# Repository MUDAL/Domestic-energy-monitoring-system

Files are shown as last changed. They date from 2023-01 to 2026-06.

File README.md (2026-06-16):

# Energy-monitoring-system

## Description  
This repository contains the code, schematics, videos, and documentation for a domestic energy monitoring system.   
The system is designed to measure and display current, voltage, power, and energy consumption at different   
points in a building, allowing users to monitor their energy usage in real-time.   

## Features   
1. Measurement of current, voltage, power, and energy consumed in a building.
2. Periodic display of measured data on an LCD.
3. Periodic logging of measured data on an SD card.
4. Periodic data upload to the cloud (ThingSpeak Server and Google Sheets).
5. Wi-Fi provisioning: To configure the SSID and password of the Wi-Fi network required by the system via a captive portal.
The captive portal also configures voltage, current, power, and energy limits.
6. The device sends notifications to the user (via an MQTT mobile application) whenever the measured parameters exceed their limits.    

## Hardware  
1. ESP32 development board  
2. PZEM-004T power module  
3. 16x2 LCD   
4. DS3231 RTC module  
5. SD card module   
6. 2GB SD card  
7. AC power socket
8. 3-pin AC power plug   
9. Jumper wires  
10. LM7805 voltage regulator  
11. LM2596 buck converter module  
12. Logic level shifter  
13. SPDT switch
14. 9V AC adapter   

## Software  
The system was developed using the ESP-IDF FreeRTOS software platform. The ESP32 was programmed using C++.    
The code provides real-time measurement and display of current, voltage, power, and energy consumption,  
as well as data logging to an SD card and data upload to the ThingSpeak server and Google Sheets.  

The software tools used in this project include:
1. Arduino IDE  
2. ESP-IDF FreeRTOS: To execute different tasks concurrently  
3. ThingSpeak: To visualize data  
4. IFTTT: To upload data to Google Sheets   
5. MQTT Alert: A mobile app to notify the user when energy limits have been exceeded.    
The smart energy monitor sends notifications to an MQTT broker (HiveMQ was used).    
The mobile app receives these notifications from the broker and alerts the user.  

Link to download the ``MQTT Alert`` application: https://play.google.com/store/apps/details?id=gigiosoft.MQTTAlert  

## Software architecture  
<p align="center">
    
</p> 

## Video Demos  
1. [System Startup](https://drive.google.com/file/d/15rAykP7Cj1u7JRBl1Hu21nxwTJwd_Z20/view?usp=sharing)  
2. [WiFi Provisioning](https://drive.google.com/file/d/1VSvE99P1S9wBY2bUv_U48mo-3ODMSw2Y/view?usp=sharing)  
3. [Load Test: Electric Iron](https://drive.google.com/file/d/1FuSU22RljI5VVFWzha-J6OE0soTpG5kJ/view?usp=sharing)  
4. [Load Test: Light Bulb](https://drive.google.com/file/d/1OdBM0wIGSkZ7wZ5bF1eTk2QWKEQir789/view?usp=sharing)  
5. [Data Logging](https://drive.google.com/file/d/1yUPShkziFqxqBmcSKSHpU0T5GiAVOwqM/view?usp=sharing)  

## Images of the prototype   

Screenshot (380)
Screenshot (382)  
Screenshot (378)  
yy  
    


     

## Credits  
1. https://randomnerdtutorials.com/esp32-esp8266-publish-sensor-readings-to-google-sheets/  
2. https://github.com/stechiez/iot_projects/blob/master/GoogleSpreadSheet_ESP32_IFTTT/ESP32_GoogleSpreadSheetIFTTT/ESP32_GoogleSpreadSheetIFTTT.ino  
3. PZEM-004T sample code and connections: https://www.nn-digital.com/en/blog/2019/11/04/example-of-the-pzem-004t-v3-v3-0-interfacing-program-using-arduino/  

## Note(s)  
1. ``preferences.begin("T-Mon",false);``. I observed that a short string as the first argument    
of ``begin`` method helps in avoiding some issues with accessing the flash memory via the   
``Preferences`` library. ``T-Mon`` was used as a short form for ``Transformer-monitor``.  
The initial application of this project was transformer monitoring but the requirements changed  
and the system was designed to monitor electrical parameters in a residential building. ``T-Mon``  
was retained but the current application of the system is ``domestic energy monitoring``.  
 
## Recommendation(s)  
1. Add a feature to prevent users from removing the SD card each time they need to view their logged data.  
One way this could be achieved is the use of ``FTP`` for file transfer from the system to a connected device  
(e.g. a PC) which will run an FTP server software.  
Another option is to set the system up as a local server that will enable other devices to download the file  
containing the logged data through a web browser.  

## Improvements made  
1. Display of ``0`` instead of ``NAN`` whenever the system isn't plugged.  
2. Replacement of code utilizing dynamic memory allocation with code utilizing static memory allocation.  
3. Replacement of batteries with an AC adapter for power supply (final modification).

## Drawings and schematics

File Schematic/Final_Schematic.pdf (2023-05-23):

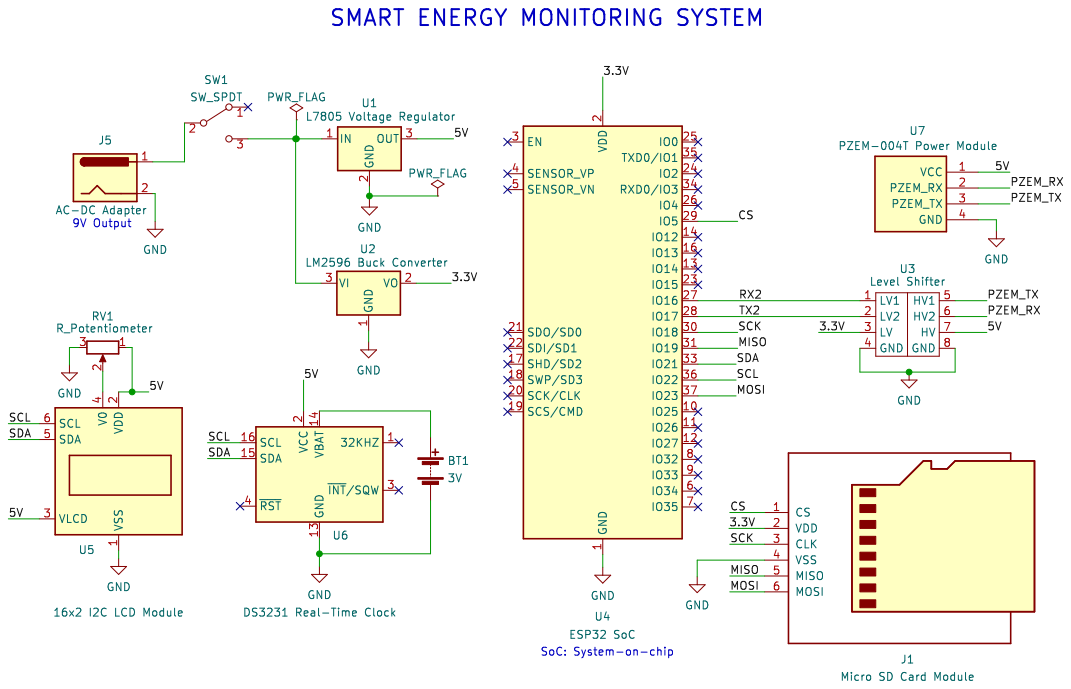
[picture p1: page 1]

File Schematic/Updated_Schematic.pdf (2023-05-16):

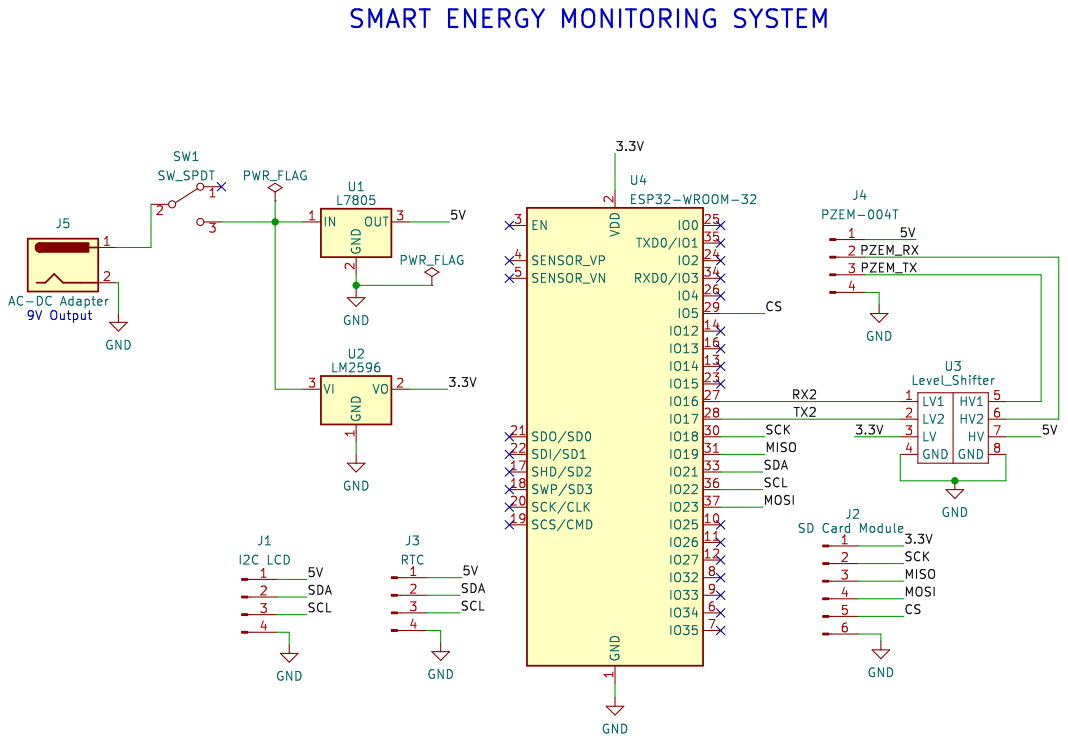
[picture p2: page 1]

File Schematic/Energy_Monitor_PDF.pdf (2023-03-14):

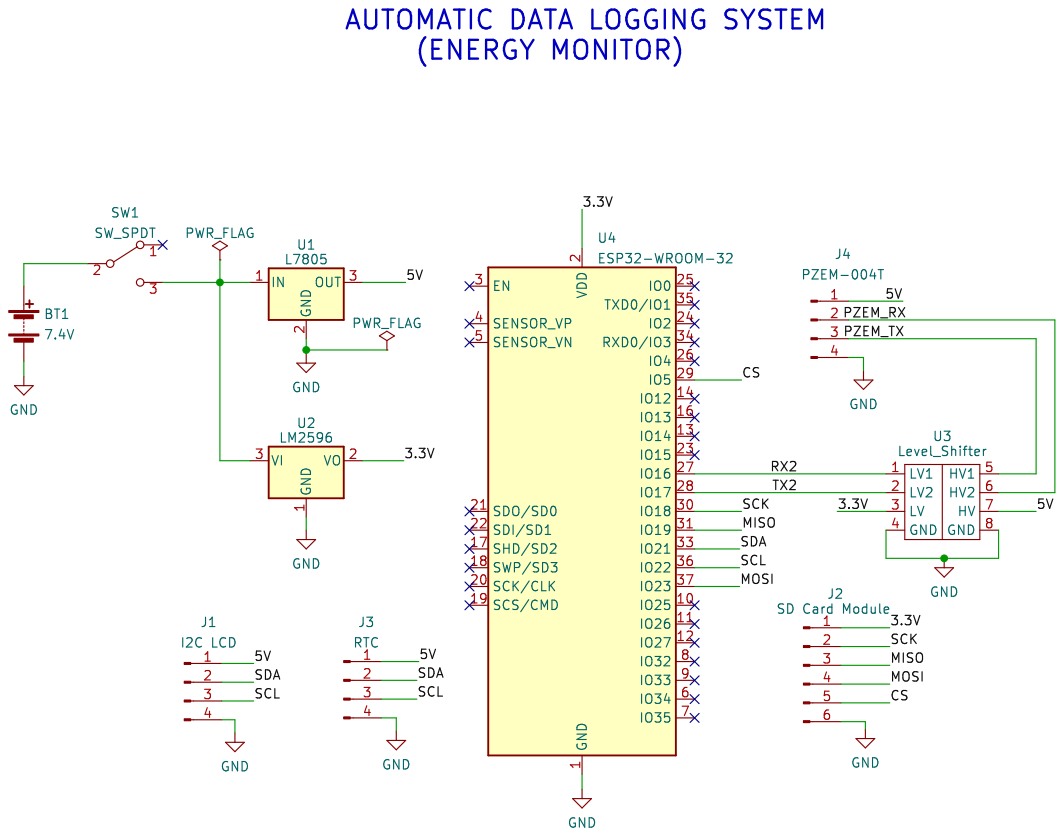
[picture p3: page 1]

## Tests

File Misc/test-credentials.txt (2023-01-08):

IFTTT:
Event name: Data
API Key: v4XEsEC37_EedkIpFihIbAvMPWIc17FXT786lTl9he

ThingSpeak:
Channel ID: 1144356
API key: 6GKXGMG5WRE8WK70

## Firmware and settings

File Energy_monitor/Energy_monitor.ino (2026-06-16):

// Author: Olaoluwa Raji

#include <WiFi.h>
#include <HTTPClient.h>
#include <Preferences.h>
#include <WiFiManager.h>
#include <PubSubClient.h>
#include <Wire.h>
#include <PZEM004Tv30.h>
#include <LiquidCrystal_I2C.h> //Version 1.1.2
#include "ThingSpeak.h" //Version 2.0.1
#include "RTClib.h" //Version 1.3.3
#include "FS.h"
#include "SD.h"
#include "SPI.h"
#include "numeric_lib.h"

//Maximum number of characters
#define SIZE_EVENT_NAME        20
#define SIZE_IFTTT_KEY         50
#define SIZE_CHANNEL_ID        30
#define SIZE_API_KEY           50
#define SIZE_TOPIC             30
#define SIZE_VOLTAGE            7
#define SIZE_CURRENT            7
#define SIZE_POWER             11
#define SIZE_ENERGY            11 
#define SIZE_CLIENT_ID         23

//Shared resources
WiFiManagerParameter eventName("0","Event name","",SIZE_EVENT_NAME);
WiFiManagerParameter iftttKey("1","IFTTT key","",SIZE_IFTTT_KEY);
WiFiManagerParameter channelId("2","ThingSpeak channel ID","",SIZE_CHANNEL_ID);
WiFiManagerParameter apiKey("3","ThingSpeak API key","",SIZE_API_KEY);
WiFiManagerParameter pubTopic("4","HiveMQ Publish topic","",SIZE_TOPIC);
WiFiManagerParameter voltageLimit("5","Voltage limit (V)","",SIZE_VOLTAGE);
WiFiManagerParameter currentLimit("6","Current limit (A)","",SIZE_CURRENT);
WiFiManagerParameter powerLimit("7","Power limit (W)","",SIZE_POWER);
WiFiManagerParameter energyLimit("8","Energy limit (kWh)","",SIZE_ENERGY);
WiFiManagerParameter subTopic("9","HiveMQ Subscription topic","",SIZE_TOPIC);
WiFiManagerParameter clientID("A","MQTT client ID","",SIZE_CLIENT_ID);
Preferences preferences; //for accessing ESP32 flash memory

//Global variables
bool isWifiTaskSuspended = false;
float pzemVoltage = 0; //in volts
float pzemCurrent = 0; //in amps
float pzemPower = 0; //in watts
float pzemEnergy = 0; //in kWh 
bool isThingSpeakOk = false;
bool isIftttOk = false;
uint8_t resetEnergyCounter = 0; //Set if data is received from MQTT broker to reset PZEM's energy counter
bool isEnergyReset = false; //Set if PZEM's energy counter was successfully reset

//Task handle(s)
TaskHandle_t wifiTaskHandle;
TaskHandle_t dispLogTaskHandle;
TaskHandle_t mqttTaskHandle;

/**
 * @brief Make an HTTP GET request to the specified server
*/
static void HttpGetRequest(const char* serverName,int* httpResponseCode) 
{ 
  HTTPClient http;
  http.begin(serverName);
  *httpResponseCode = http.GET();
  http.end();  
}

/**
 * @brief Store new data (e.g. IFTTT and ThingSpeak credentials) to specified 
 * location in ESP32's flash memory if the new credentials are different from 
 * the previous.  
*/
static void StoreNewFlashData(const char* flashLoc,const char* newData,
                              const char* oldData,uint8_t dataSize)
{
  if(strcmp(newData,"") && strcmp(newData,oldData))
  {
    preferences.putBytes(flashLoc,newData,dataSize);
  }
}

/**
 * @brief Appends data to a file stored in an SD card
 * @param path: path to the file to be written
 * @param message: data to be appended to the file
 * @return None
*/
static void SD_AppendFile(const char* path,const char* message)
{
  File file = SD.open(path,FILE_APPEND);
  file.print(message);
  file.close();
}

/**
 * @brief Suspend WiFi task if it wasn't previously suspended.
*/
static void SuspendWiFiTask(void)
{
  if(!isWifiTaskSuspended)
  {
    vTaskSuspend(wifiTaskHandle);
    isWifiTaskSuspended = true;
  }  
}

/**
 * @brief Resume WiFi task if it was previously suspended.
*/
static void ResumeWiFiTask(void)
{
  if(isWifiTaskSuspended)
  {
    vTaskResume(wifiTaskHandle);
    isWifiTaskSuspended = false;
  }
}

/**
 * @brief Notify the user if connection to a server (ThingSpeak or IFTTT) is
 * OK i.e. data was successfully sent to the server.
*/
static void NotifyUserIfConnIsOk(LiquidCrystal_I2C& lcd,char* server,bool* isServerOk)
{
  if(*isServerOk)
  {
    lcd.clear();
    lcd.print(server);
    lcd.setCursor(0,1);
    lcd.print("SUCCESS");
    *isServerOk = false;
    vTaskDelay(pdMS_TO_TICKS(1500));
    lcd.clear();
  }
}

/**
 * @brief Reset the system after specified time in milliseconds if the 
 * readings from the PZEM module are invalid.
*/
static void ResetIfReadingsAreInvalid(uint32_t timeMillis)
{
  static bool prevInvalid;
  static uint32_t prevTime;
  bool isInvalid = (lround(pzemVoltage) == 0) && (lround(pzemCurrent) == 0) &&
                   (lround(pzemPower) == 0) && (lround(pzemEnergy) == 0);
  
  if(isInvalid && !prevInvalid)
  {
    Serial.println("Invalid readings, system will reset soon");
    prevInvalid = true;
    prevTime = millis();
  }
  if(prevInvalid && ((millis() - prevTime) >= timeMillis))
  {
    if(isInvalid)
    {
      esp_restart();
    }
    prevInvalid = false;    
  }
}

void setup() 
{
  setCpuFrequencyMhz(80);
  Serial.begin(115200);
  preferences.begin("T-Mon",false); 
  //Create tasks
  xTaskCreatePinnedToCore(WiFiManagementTask,"",7000,NULL,1,&wifiTaskHandle,1);
  xTaskCreatePinnedToCore(ApplicationTask,"",50000,NULL,1,NULL,1);
  xTaskCreatePinnedToCore(DisplayAndLogTask,"",40000,NULL,1,&dispLogTaskHandle,1);
  xTaskCreatePinnedToCore(MqttTask,"",7000,NULL,1,&mqttTaskHandle,1);
}

void loop() 
{
}

/**
 * @brief Manages WiFi configurations (STA and AP modes). Connects
 * to an existing/saved network if available, otherwise it acts as
 * an AP in order to receive new network credentials.
*/
void WiFiManagementTask(void* pvParameters)
{
  const uint16_t accessPointTimeout = 50000; //millisecs
  static WiFiManager wm;
  WiFi.mode(WIFI_STA);  
  wm.addParameter(&eventName);
  wm.addParameter(&iftttKey);
  wm.addParameter(&channelId);
  wm.addParameter(&apiKey);
  wm.addParameter(&voltageLimit);
  wm.addParameter(&currentLimit);
  wm.addParameter(&powerLimit);
  wm.addParameter(&energyLimit);    
  wm.addParameter(&pubTopic);
  wm.addParameter(&subTopic);
  wm.addParameter(&clientID);
  wm.setConfigPortalBlocking(false);
  wm.setSaveParamsCallback(WiFiManagerCallback);   
  //Auto-connect to previous network if available.
  //If connection fails, ESP32 goes from being a station to being an access point.
  Serial.print(wm.autoConnect("Energy-Monitor")); 
  Serial.println("-->WiFi status");   
  bool accessPointMode = false;
  uint32_t startTime = 0;    
  
  while(1)
  {
    wm.process();
    if(WiFi.status() != WL_CONNECTED)
    {
      if(!accessPointMode)
      {
        if(!wm.getConfigPortalActive())
        {
          wm.autoConnect("Energy-Monitor"); 
        }
        accessPointMode = true; 
        startTime = millis(); 
      }
      else
      {
        //reset after a timeframe (device shouldn't spend too long as an access point)
        if((millis() - startTime) >= accessPointTimeout)
        {
          Serial.println("\nAP timeout reached, system will restart for better connection");
          vTaskDelay(pdMS_TO_TICKS(1000));
          esp_restart();
        }
      }
    }
    else
    {
      if(accessPointMode)
      {   
        accessPointMode = false;
        Serial.println("Successfully connected, system will restart now");
        vTaskDelay(pdMS_TO_TICKS(1000));
        esp_restart();
      }
    }    
  }
}

/**
 * @brief 
 * - Gets PZEM-004T data.
 * 
 * - Uploads PZEM-004T module's data to Google sheets and ThingSpeak
 *   via HTTP requests. IFTTT serves as an intermediary 
 *   between the ESP32 and Google sheets.  
*/
void ApplicationTask(void* pvParameters)
{
  static WiFiClient wifiClient;
  static PZEM004Tv30 pzem(&Serial2,16,17);
  static char iftttServerPath[300];
  ThingSpeak.begin(wifiClient);
  int httpCode; //HTTP response code
  //Previously stored data (in ESP32's flash)
  char prevEventName[SIZE_EVENT_NAME] = {0};
  char prevIftttKey[SIZE_IFTTT_KEY] = {0};
  char prevChannelId[SIZE_CHANNEL_ID] = {0};
  char prevApiKey[SIZE_API_KEY] = {0};

  uint32_t prevPzemTime = millis();  
  uint32_t prevConnectTime = millis();
 
  while(1)
  {
    //Suspend WiFi Management task if the system is already.... 
    //connected to a Wi-Fi network
    if(WiFi.status() == WL_CONNECTED && !isWifiTaskSuspended)
    {
      Serial.println("WIFI TASK: SUSPENDED");
      vTaskSuspend(wifiTaskHandle);
      isWifiTaskSuspended = true;
    }
    else if(WiFi.status() != WL_CONNECTED && isWifiTaskSuspended)
    {
      Serial.println("WIFI TASK: RESUMED");
      vTaskResume(wifiTaskHandle);
      isWifiTaskSuspended = false;
    }
    
    //Reset PZEM's energy counter if MQTT command is received
    if(resetEnergyCounter)
    {
      isEnergyReset = pzem.resetEnergy();
      resetEnergyCounter = 0;
    }
    
    bool hasPzemBeenRead = false;
    //Critical section [Get data from PZEM module periodically]
    if((millis() - prevPzemTime) >= 2500)
    {
      SuspendWiFiTask();
      vTaskSuspend(mqttTaskHandle);
      vTaskSuspend(dispLogTaskHandle);
      
      pzemVoltage = pzem.voltage(); //in volts
      pzemCurrent = pzem.current(); //in amps
      pzemPower = pzem.power(); //in watts
      pzemEnergy = pzem.energy(); //in kWh
      
      SetToZeroIfNaN(&pzemVoltage);
      SetToZeroIfNaN(&pzemCurrent);
      SetToZeroIfNaN(&pzemPower);
      SetToZeroIfNaN(&pzemEnergy);
      
      ResumeWiFiTask();
      vTaskResume(mqttTaskHandle);
      vTaskResume(dispLogTaskHandle);
      prevPzemTime = millis();
      hasPzemBeenRead = true;
    }
    
    //Reset the system in case valid readings aren't read from the PZEM module...
    //despite the system's 3-pin plug being connected to an AC source.
    if(WiFi.status() == WL_CONNECTED && hasPzemBeenRead)
    {
      ResetIfReadingsAreInvalid(10000);
    }
    
    //Send data to the cloud [periodically]      
    if(WiFi.status() == WL_CONNECTED && ((millis() - prevConnectTime) >= 20000))
    {
      preferences.getBytes("0",prevEventName,SIZE_EVENT_NAME);
      preferences.getBytes("1",prevIftttKey,SIZE_IFTTT_KEY);  
      preferences.getBytes("2",prevChannelId,SIZE_CHANNEL_ID);
      preferences.getBytes("3",prevApiKey,SIZE_API_KEY); 
      
      //Encode PZEM data to be sent to ThingSpeak
      ThingSpeak.setField(1,pzemVoltage);
      ThingSpeak.setField(2,pzemCurrent); 
      ThingSpeak.setField(3,pzemPower); 
      ThingSpeak.setField(4,pzemEnergy);
      
      uint32_t idInteger = 0;
      StringToInteger(prevChannelId,&idInteger); //Convert channel ID from string to integer
      httpCode = ThingSpeak.writeFields(idInteger,prevApiKey); //Send data to ThingSpeak
      if(httpCode == HTTP_CODE_OK)
      {
        isThingSpeakOk = true;
      }
      else
      {
        isThingSpeakOk = false;
      }  

      char voltageBuff[SIZE_VOLTAGE] = {0};
      char currentBuff[SIZE_CURRENT] = {0};
      char powerBuff[SIZE_POWER] = {0};
      char energyBuff[SIZE_ENERGY] = {0};
      
      FloatToString(pzemVoltage,voltageBuff,2);
      FloatToString(pzemCurrent,currentBuff,2);
      FloatToString(pzemPower,powerBuff,2);
      FloatToString(pzemEnergy,energyBuff,3);

      strcat(iftttServerPath,"http://maker.ifttt.com/trigger/");
      strcat(iftttServerPath,prevEventName);
      strcat(iftttServerPath,"/with/key/");
      strcat(iftttServerPath,prevIftttKey);
      strcat(iftttServerPath,"?value1=");
      strcat(iftttServerPath,voltageBuff);
      strcat(iftttServerPath,"V&value2=");
      strcat(iftttServerPath,currentBuff);
      strcat(iftttServerPath,"A&value3=");
      strcat(iftttServerPath,powerBuff);
      strcat(iftttServerPath,"W_");
      strcat(iftttServerPath,energyBuff);
      strcat(iftttServerPath,"kWh");
      
      HttpGetRequest(iftttServerPath,&httpCode); //Send PZEM data to IFTTT
      uint32_t iftttServerPathLen = strlen(iftttServerPath);
      memset(iftttServerPath,'\0',iftttServerPathLen);
      if(httpCode == HTTP_CODE_OK) 
      {
        isIftttOk = true;
      } 
      else 
      {
        isIftttOk = false;
      }     
      prevConnectTime = millis(); 
    }
    vTaskDelay(pdMS_TO_TICKS(50));
  }
}

/**
 * @brief Displays PZEM-004T's readings on the LCD. 
 * Stores data on an SD card (with date and time).
*/
void DisplayAndLogTask(void* pvParameters)
{   
  static LiquidCrystal_I2C lcd(0x27,16,2); 
  static RTC_DS3231 rtc;  
  static char sdCardData[120];
  static DateTime dateTime;
  rtc.begin();
    
  //LCD init and startup message
  lcd.init();
  lcd.backlight();
  lcd.setCursor(1,0);
  lcd.print("Energy Monitor");
  vTaskDelay(pdMS_TO_TICKS(1500)); 
  lcd.clear();

  //SD Init
  //SD: Uses SPI pins 23(MOSI),19(MISO),18(CLK) and 5(CS)
  const uint8_t chipSelectPin = 5;
  pinMode(chipSelectPin,OUTPUT);
  digitalWrite(chipSelectPin,HIGH);
  if(SD.begin(chipSelectPin))
  {
    lcd.print("SD INIT: ");
    lcd.setCursor(0,1);
    lcd.print("SUCCESS");
  }
  else
  {
    lcd.print("SD INIT: ");
    lcd.setCursor(0,1);
    lcd.print("FAILURE");  
  }
  vTaskDelay(pdMS_TO_TICKS(1500)); 
  lcd.clear();
  
  //Simple FSM to periodically change parameters being displayed.
  const uint8_t displayState1 = 0;
  const uint8_t displayState2 = 1;
  uint8_t displayState = displayState1;
  
  uint32_t prevTime = millis();
  uint32_t prevLogTime = millis();
   
  while(1)
  {
    //Display PZEM readings
    lcd.setCursor(0,0);
    switch(displayState)
    {
      case displayState1: //Display voltage and current
        lcd.print("Volts: ");
        lcd.print(pzemVoltage,2);
        lcd.setCursor(0,1);
        lcd.print("Amps: ");
        lcd.print(pzemCurrent,2);
        if((millis() - prevTime) >= 4000)
        {
          displayState = displayState2;
          prevTime = millis();
          lcd.clear();
        }
        break;
        
      case displayState2: //Display power and energy
        lcd.print("Watts: ");
        lcd.print(pzemPower,2);
        lcd.setCursor(0,1);
        lcd.print("kWh: ");
        lcd.print(pzemEnergy,3);
        if((millis() - prevTime) >= 4000)
        {
          displayState = displayState1;
          prevTime = millis();
          lcd.clear();
        }
        break;
    }   
    NotifyUserIfConnIsOk(lcd,"ThingSpeak",&isThingSpeakOk);
    NotifyUserIfConnIsOk(lcd,"IFTTT",&isIftttOk);
    //Log data to SD card periodically
    if((millis() - prevLogTime) >= 20000)
    {
      //Get current date and time and concatenate with PZEM readings
      dateTime = rtc.now(); 
                          
      char dayBuff[3] = {0};
      char monthBuff[3] = {0};
      char yearBuff[5] = {0};
      char hourBuff[3] = {0};
      char minuteBuff[3] = {0};
      char voltageBuff[SIZE_VOLTAGE] = {0};
      char currentBuff[SIZE_CURRENT] = {0};
      char powerBuff[SIZE_POWER] = {0};
      char energyBuff[SIZE_ENERGY] = {0};
      
      IntegerToString(dateTime.day(),dayBuff);
      IntegerToString(dateTime.month(),monthBuff);
      IntegerToString(dateTime.year(),yearBuff);
      IntegerToString(dateTime.hour(),hourBuff);
      IntegerToString(dateTime.minute(),minuteBuff);
      FloatToString(pzemVoltage,voltageBuff,2);
      FloatToString(pzemCurrent,currentBuff,2);
      FloatToString(pzemPower,powerBuff,2);
      FloatToString(pzemEnergy,energyBuff,3);

      strcat(sdCardData,dayBuff);
      strcat(sdCardData,"/");
      strcat(sdCardData,monthBuff);
      strcat(sdCardData,"/");
      strcat(sdCardData,yearBuff);
      strcat(sdCardData," ");
      strcat(sdCardData,hourBuff);
      strcat(sdCardData,":");
      strcat(sdCardData,minuteBuff);
      strcat(sdCardData," ---> ");
      strcat(sdCardData,voltageBuff);
      strcat(sdCardData,"V, ");
      strcat(sdCardData,currentBuff);
      strcat(sdCardData,"A, ");
      strcat(sdCardData,powerBuff);
      strcat(sdCardData,"W, ");
      strcat(sdCardData,energyBuff);
      strcat(sdCardData,"kWh\n");
      
      SD_AppendFile("/project_file.txt",sdCardData);
      uint32_t sdCardDataLen = strlen(sdCardData);
      memset(sdCardData,'\0',sdCardDataLen);
      
      lcd.clear();
      lcd.print("LOGGING TO SD");
      prevLogTime = millis();
      vTaskDelay(pdMS_TO_TICKS(1500));
      lcd.clear();      
    }     
    //Display message if PZEM's energy counter was successfully reset
    if(isEnergyReset)
    {
      lcd.clear();
      lcd.print("ENERGY RESET:");
      lcd.setCursor(0,1);
      lcd.print("SUCCESS");
      isEnergyReset = false;
      vTaskDelay(pdMS_TO_TICKS(1500));
      lcd.clear();
    }
  }
}

/**
 * @brief Handles communication with the HiveMQ broker.
*/
void MqttTask(void* pvParameters)
{
  static WiFiClient wifiClient;
  static PubSubClient mqttClient(wifiClient);
  static char dataToPublish[250];
  
  char prevPubTopic[SIZE_TOPIC] = {0};
  char prevSubTopic[SIZE_TOPIC] = {0};
  char prevClientID[SIZE_CLIENT_ID] = {0};
  const char *mqttBroker = "broker.hivemq.com";
  const uint16_t mqttPort = 1883;  
  uint32_t prevTime = millis();
            
  while(1)
  {
    if(WiFi.status() == WL_CONNECTED)
    {       
      if(!mqttClient.connected())
      {
        memset(prevPubTopic,'\0',SIZE_TOPIC);
        memset(prevSubTopic,'\0',SIZE_TOPIC);
        memset(prevClientID,'\0',SIZE_CLIENT_ID);
        preferences.getBytes("4",prevPubTopic,SIZE_TOPIC);  
        preferences.getBytes("9",prevSubTopic,SIZE_TOPIC);  
        preferences.getBytes("A",prevClientID,SIZE_CLIENT_ID);  
        mqttClient.setServer(mqttBroker,mqttPort);
        mqttClient.setCallback(MqttCallback);
        while(!mqttClient.connected())
        {
          if(mqttClient.connect(prevClientID))
          {
            Serial.println("Connected to HiveMQ broker");
            mqttClient.subscribe(prevPubTopic);
          }
        } 
      }
      else
      {
        if((millis() - prevTime) >= 500)
        {
          char prevVoltageLimit[SIZE_VOLTAGE] = {0};
          char prevCurrentLimit[SIZE_CURRENT] = {0};
          char prevPowerLimit[SIZE_POWER] = {0};
          char prevEnergyLimit[SIZE_ENERGY] = {0};  
           
          preferences.getBytes("5",prevVoltageLimit,SIZE_VOLTAGE);
          preferences.getBytes("6",prevCurrentLimit,SIZE_CURRENT);
          preferences.getBytes("7",prevPowerLimit,SIZE_POWER);
          preferences.getBytes("8",prevEnergyLimit,SIZE_ENERGY); 
        
          strcat(dataToPublish,"Limits:\n");
          strcat(dataToPublish,prevVoltageLimit);
          strcat(dataToPublish,"V\n");
          strcat(dataToPublish,prevCurrentLimit);
          strcat(dataToPublish,"A\n");          
          strcat(dataToPublish,prevPowerLimit);
          strcat(dataToPublish,"W\n"); 
          strcat(dataToPublish,prevEnergyLimit);
          strcat(dataToPublish,"kWh\n\n"); 

          float voltageLim = 0;
          float currentLim = 0;
          float powerLim = 0;
          float energyLim = 0;
          
          StringToFloat(prevVoltageLimit,&voltageLim);
          StringToFloat(prevCurrentLimit,&currentLim);
          StringToFloat(prevPowerLimit,&powerLim);
          StringToFloat(prevEnergyLimit,&energyLim);

          bool isVoltageAbnormal = lround(pzemVoltage * 100) > lround(voltageLim * 100);
          bool isCurrentAbnormal = lround(pzemCurrent * 100) > lround(currentLim * 100);
          bool isPowerAbnormal = lround(pzemPower * 100) > lround(powerLim * 100);
          bool isEnergyAbnormal = lround(pzemEnergy * 1000) > lround(energyLim * 1000);

          strcat(dataToPublish,"Abnormal:\n");
          if(isVoltageAbnormal)
          {
            char voltageBuff[SIZE_VOLTAGE] = {0};
            FloatToString(pzemVoltage,voltageBuff,2);
            strcat(dataToPublish,voltageBuff);
            strcat(dataToPublish,"V\n");
          }
          if(isCurrentAbnormal)
          {
            char currentBuff[SIZE_CURRENT] = {0};
            FloatToString(pzemCurrent,currentBuff,2);
            strcat(dataToPublish,currentBuff);
            strcat(dataToPublish,"A\n");
          }
          if(isPowerAbnormal)
          {
            char powerBuff[SIZE_POWER] = {0};
            FloatToString(pzemPower,powerBuff,2);
            strcat(dataToPublish,powerBuff);
            strcat(dataToPublish,"W\n");
          }
          if(isEnergyAbnormal)
          {
            char energyBuff[SIZE_ENERGY] = {0};
            FloatToString(pzemEnergy,energyBuff,3);
            strcat(dataToPublish,energyBuff);
            strcat(dataToPublish,"kWh\n");
          }

          if(isVoltageAbnormal || isCurrentAbnormal || isPowerAbnormal || isEnergyAbnormal)
          {
            mqttClient.publish(prevSubTopic,dataToPublish); 
          }
          memset(dataToPublish,'\0',strlen(dataToPublish));
          prevTime = millis();
        }   
        mqttClient.loop(); //handles mqtt callback
      }
    }
  }
}
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

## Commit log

2022-11-24 Create Power Transformer Logging.pdsprj
2022-12-27 Update Transformer_monitor.ino
    - Added MQTT functionality for resetting PZEM's energy counter
    [Transformer_monitor.ino]
2023-02-05 Added schematic
    [Energy_Monitor.kicad_pcb, Energy_Monitor.kicad_sch]
2023-02-05 Adjusted schematic
2023-03-14 Update
    - Added a switch to the design
    - Changed SD card logging interval to 20s
    [Energy_Monitor.kicad_sch]
2023-03-19 Update Energy_monitor.ino
    - Refactored the codebase
    - Replaced dynamic memory allocation with static memory allocation
    - Changed all occurrences of ``NAN`` to 0
    [Energy_monitor.ino]
2023-05-23 Create Old schematic diagrams
